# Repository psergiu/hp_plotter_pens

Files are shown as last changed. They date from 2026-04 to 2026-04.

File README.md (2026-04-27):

# HP Plotter Pens

3D-printed HP plotter pen models, using ballpoint pen refils.
Pros:
* easily available refills in multiple colors
* very thin lines
* less prone to dry out than ink pens
* much more writing distance per pen compared to ink pens
Cons:
* requires thicker paper else ball might not roll and leave ink on paper
* not suitable for points of very short lines (<1mm)
* very thin lines (not suitable for filling polygons or thick lines)

## Compatibility
The pens are compatible with the follwing plotters: 
* HP 9872
* HP 7440A ColorPro
* HP 7225
* HP 7470A
* HP 7475A
* HP 7550 (can be used with full-size uncut refills)
* HP 7090A Measurement Plotting System
* DEC LVP16
* IBM 7372
* IBM 6180

## Included models
### Bic Cristal refills
To be used with refills taken out of from Bic Cristal pens, available in multiple colors. Example: 
* https://www.amazon.com/BIC-MSBAPP241-Ballpoint-Assorted-24-Count/dp/B075CGYY5P/
* https://www.amazon.com/BIC-Cristal-Multicolour-Ballpoint-Point/dp/B07LF68GPR/

Cut off refill tube 3-4 mm above top of printed pen body - if you used white PETG, you can smear ink from the cut-off session on top of pen for easier identification. Warning: messy

### "Beadable Pen" refills
Those are short refills for the so-called "Badable" DIY pens. Available in black, blue & red in packs of 100+. Example:
* https://www.amazon.com/PASISIBICK-Plastic-Beadable-Refills-Writing/dp/B0CYLHZYT6/

The ink level in the refill tube is usually at the perfect so the tube can be shortened without causing a mess.

### Gell Ink refills
Work-In-Progress !

For gel pens, includes a stopper to keep the refill in place. 
Not fully tested yet, gel ink tends to seep out from the cut-off tubes if pens are not kept vertically and make a huge mess.

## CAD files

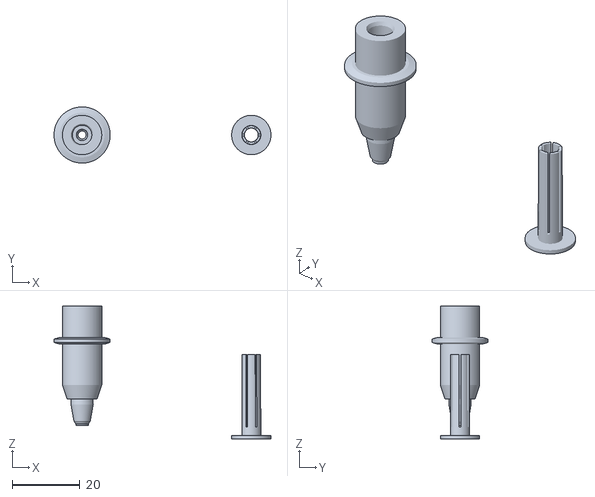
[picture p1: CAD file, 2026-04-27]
HP_pen-gel_refill.stl
64.1 x 16.6 x 39.2

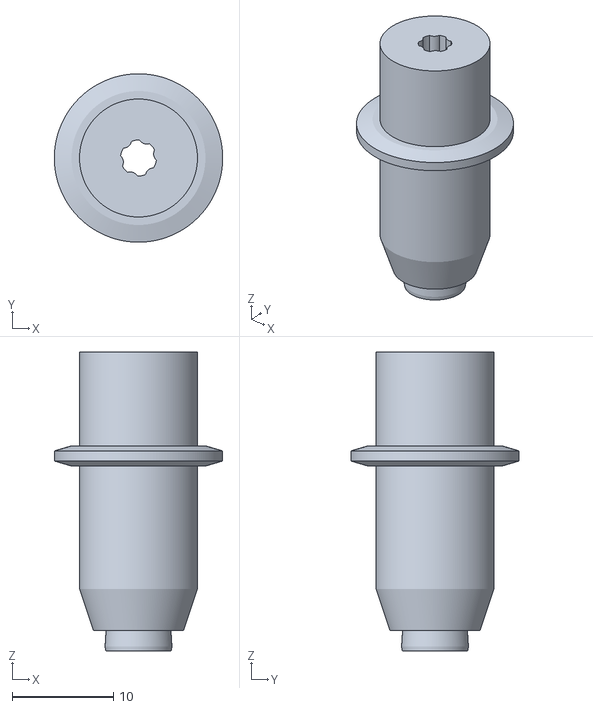
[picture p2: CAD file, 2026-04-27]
HP_pen-bic_cristal.stl
16.6 x 16.6 x 29.5

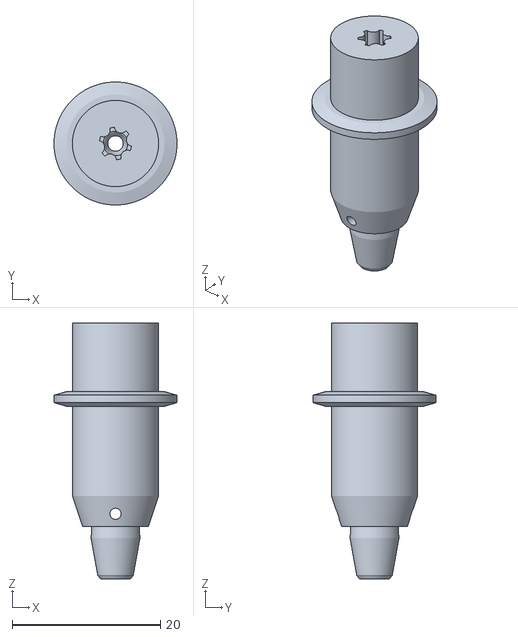
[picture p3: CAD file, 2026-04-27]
HP_pen-beadable_refill.stl
16.6 x 16.6 x 34.6

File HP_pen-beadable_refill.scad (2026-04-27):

// Beadable pen refill (62mm long, 44mm tip-to-end-of-ink)
// HP Plotter pen adapter 
//  by Sergiu Partenie
// - insert refill from top down
// - cut refill height to fit in pen path of plotter
// - print with tip facing up and concentric supports
// - reccomended material: PETg or similar non-brittle

$fn= 180;

//    ..............., pen_top_diameter ...............> |   | <,,  
//    :    ........... pen_diam                          |   |
//    :    :                                             |   |
//     _____  ........ top_cut_off_height                |   |
//    ||   |                                             |   |
//    ||   |                                             |   |
//    ||   |___                                          |   |
//    ||    __/  ..... ~ 27.7 mm to paper                |   |
//    ||   |                                             |   |
//    ||   |                                             |   |
//    ||   |                                             |   |
//    ||   |                                             |   |
//     |   |                                             [   ]
//     | . /  .........wiew_hole_height                  |   |
//   +-+ _/ .......... height_where_pen_diameter_change. \___/
//   |  /                                                 | | 
//   | /  ............ tip_height                         | |   
//   //                pen_bottom_diameter..............> | | <...
//  /'   ............. bottom_cut_off_height              | |
//                                                        \ /
// ------------------- ( paper ) --------------------------*--


total_body_height = 43.25 ; // fixed value, Official HP pen max height
pen_diam = 11.63 ; // official=11.5, HP pens=11.6. Adjust for filament shrinkage
pen_top_diameter = 4.35 ; 
pen_bottom_diameter = 3.25 ; 
tip_height = 2 ; // top of cone to squeeze metal tip for perfectly centered fit
pen_tip_diameter = 0 ; // adjust to enlarge metal tip squeeze cone. Default: 0

diameter_spacing = 0.05 ; // increase = easier to slide the pen. If you set it to 0 it will be very hard to get the pen in.

height_where_pen_diameter_change = 21.7 ; // Measured from the tip (ie. paper)
bottom_cut_off_height = height_where_pen_diameter_change - (22-5) ; 
top_cut_off_height = total_body_height - 4 ; // Top part of the pen, lower to allow handling refill tube

wiew_hole_height = 13.5 ; // height of view hole (for visually checking if refill is spent)

BodyOutline = [                     // X values = (measured diameter)/2, Y as distance from
    [0.0,0.0],                      //  0 fiber pen tip
//  [2.0/2,1.4],                    //  1 ... taper (not buildable)
    [1.0/2,0.005],                  //  1 ... faked point to remove taper
    [2.0/2,0.0],[2.0/2,2.7],        //  2 ... cylinder
    [3.7/2,2.7],[3.7/2,4.45],       //  4 tip surround
    [4.8/2,5.2],                    //  5 chamfer
    [6.6/2,10.2],                   //  6 seal seat    
    [6.4/2,11.8],                   //  7 rubber seal face
    [8.9/2,11.8],                   //  8 cap seat
    [pen_diam/2,15.9],              //  9 taper to body
    [pen_diam/2,28.0],              // 10 lower body
    [13.2/2,28.0],[16.6/2,28.5],    // 11 lower flange = 0.5
    [16.6/2,29.5],[13.2/2,30.0],    // 13 flange rim = 1.0
    [pen_diam/2,30.0],              // 15 upper flange = 0.5
    [pen_diam/2,43.25],             // 16 upper body
    [0.0,43.25]                     // 17 lid over reservoir
    ];

module adapter_body() {
 render(convexity=10)
        rotate_extrude()
            polygon(points=BodyOutline);
}

module adapter_minus_pen() {
    difference() {
        color ("white", 0.2) adapter_body () ;

        color ("red") translate([0,0,height_where_pen_diameter_change])
                    cylinder(r= (pen_top_diameter+diameter_spacing)/2, 
                             h= 100);

         color ("blue") translate([0,0,bottom_cut_off_height+tip_height])
                            cylinder(r=(pen_bottom_diameter+diameter_spacing)/2, 
                                 h=height_where_pen_diameter_change);

         // conical taper to squeeze metal refill tip
         color ("violet") translate([0,0,0.5]) cylinder(r1=(pen_tip_diameter+diameter_spacing)/2,
                                   r2=(pen_bottom_diameter+diameter_spacing)/2,
                                h=bottom_cut_off_height+tip_height);

        translate ([0, 0, bottom_cut_off_height/2]) 
            cube ([20, 20, bottom_cut_off_height], center=true) ;

        translate ([0, 0, 50/2 + top_cut_off_height]) 
            cube ([20, 20, 50], center=true) ;
    }
}

// to hold refill tube in place while also allowing easy replacement
//  if refill tube is moving freely it creates incorrect draw paths 
module guide() {
 translate([pen_bottom_diameter/2,-1.8,height_where_pen_diameter_change])
    cylinder(d=1.8,h=top_cut_off_height-height_where_pen_diameter_change);
}

union(){
 difference(){
  adapter_minus_pen();
  // sideways hole for visual inspection of ink level
  rotate([90,0,0])
    translate([0,wiew_hole_height,0])
     cylinder(d=1.5, h=12, center=true);
 }
 guide();
 rotate([0,0,60]) guide();
 rotate([0,0,120]) guide();
 rotate([0,0,180]) guide();
 rotate([0,0,240]) guide();
 rotate([0,0,300]) guide();
}

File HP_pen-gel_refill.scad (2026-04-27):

// Gel pen refill (128mm long, 7mm tip)
// HP Plotter pen adapter
//  by Sergiu Partenie
// - insert refill from top down
// - cut refill height to fit in pen path of plotter
// - print with tip facing up and concentric supports 

$fn= 180;

//                    refill_diam_tube ...............> |   | <..
//    ............... refill_diam_b ...............     |   |  
//    :   ........... pen_diam                    :     |   |
//    :   :                                       :     |   |
//     ____  ........ top_cut_off_height          :     |   |
//    /   |                                       :     |   |
//    |   |                                       :     |   |
//    |   |___                                    :     |   |
//    |    __/  ..... ~ 27.7 mm to paper          :     |   |
//    |   |                                       :     |   |
//    |   |                                       :     |   |
//    |   |                                       :     |   |
//    |   |                                       :     |   |
//    |   |                                       :.> __|___|__ <..
//  +-+   /   ....... refill_height_b ............... |_______|
//  |   _/                                              |   |
//  |  /              refill_diam_a ..................> |   | <....
// ++ /    .......... refill_height_a ..................\___/   
// | /                refill_diam_tip .................> | | <.....
// -'   ............. bottom_cut_off_height              | |
//                                                       \ /
// ------------------ ( paper ) --------------------------*--

total_body_height = 43.25 ; // fixed value, Official HP pen max height
pen_diam = 11.63 ; // official=11.5, HP pens=11.6. Adjust for filament shrinkage
bottom_cut_off_height = 4; // Measured from the tip (ie. paper)
top_cut_off_height = total_body_height - 4 ; // Top part of the pen, shorten

refill_diam_tip = 2.3 ; // width of bottom (tip) pen hole. Should be a tight (but removable) fit
refill_height_a = 7 ; // distance from paper where metal tip enters plastic tube 
refill_diam_a = 3.25; // diameter of plastic tube holding metal tip
refill_height_b = 13.76 ; // (0.16mm x 86 layers) Measured from the tip (ie. paper) to bottom of refill flange
refill_diam_b = 5.65 ; // width of the refill flange
refill_diam_tube = 4 ; // width of long refill tube

diameter_spacing = 0.05 ; // increase = easier to slide the refill. If you set it to 0 it will be very hard to get the refill in.

BodyOutline = [                     // X values = (measured diameter)/2, Y as distance from
    [0.0,0.0],                      //  0 fiber pen tip
//  [2.0/2,1.4],                    //  1 ... taper (not buildable)
    [1.0/2,0.005],                  //  1 ... faked point to remove taper
    [2.0/2,0.0],[2.0/2,2.7],        //  2 ... cylinder
    [3.7/2,2.7],[3.7/2,4.45],       //  4 tip surround
    [4.8/2,5.2],                    //  5 chamfer
    [6.6/2,10.2],                   //  6 seal seat    
    [6.4/2,11.8],                   //  7 rubber seal face
    [8.9/2,11.8],                   //  8 cap seat
    [pen_diam/2,15.9],              //  9 taper to body
    [pen_diam/2,28.0],              // 10 lower body
    [13.2/2,28.0],[16.6/2,28.5],    // 11 lower flange = 0.5
    [16.6/2,29.5],[13.2/2,30.0],    // 13 flange rim = 1.0
    [pen_diam/2,30.0],              // 15 upper flange = 0.5
    [pen_diam/2,43.25],             // 16 upper body
    [0.0,43.25]                     // 17 lid over reservoir
    ];

module adapter_body() {
 render(convexity=10)
        rotate_extrude()
            polygon(points=BodyOutline);
}

module adapter_minus_refill()
{
 difference()
  {
   color ("white", 0.2) adapter_body () ;

   // top pen hole
   color ("red")
    translate([0,0,refill_height_b])
     cylinder(d=refill_diam_b+diameter_spacing*2, h=100);

   // bottom pen hole
   color ("blue")
    translate([0,0,bottom_cut_off_height-diameter_spacing])
     cylinder(d=refill_diam_tip+diameter_spacing,h=refill_height_b-bottom_cut_off_height+2*diameter_spacing);

   // bottom (tip) cut-off line
   translate ([0, 0, bottom_cut_off_height/2]) 
    cube ([20, 20, bottom_cut_off_height], center=true) ;

   // top cut-off line
   translate ([0, 0, 50/2 + top_cut_off_height]) 
    cube ([20, 20, 50], center=true) ;

   // transition for easier refill insertion - bottom
   color ("violet")
    translate([0,0,refill_height_a-0.5])
     cylinder(d1=refill_diam_tip+diameter_spacing,d2=refill_diam_a,h=0.51);
  
   // tapered hole for plastic tube
   color ("blue") 
    translate([0,0,refill_height_a])
     cylinder(d1=refill_diam_a,d2=refill_diam_a+0.1,h=refill_height_b-refill_height_a+0.1);
     
   // transition for easier refill insertion - middle  
   color ("violet")
    translate([0,0,refill_height_b-0.5])
     cylinder(d1=refill_diam_a,d2=refill_diam_a+0.5,h=0.51);

   // transition for easier refill insertion - top   
   color ("violet")
    translate([0,0,top_cut_off_height-1])
     cylinder(d1=refill_diam_b,d2=refill_diam_b+1,h=1.1);
  }
}


// adapter
difference()
 {
  union()
   {
    adapter_minus_refill() ;
    // optional parts to add
   }
  // debug section view, comment out for final print
  // cube([20,20,100]);
 }


// refill stopper
translate([50,0,0])
 difference()
  {
    union()
     {
       // bottom flange
       cylinder(d=pen_diam, h=1);
       // stopper body, tapered
       cylinder(d1=refill_diam_b,d2=refill_diam_b-diameter_spacing-0.1,h=1+top_cut_off_height-refill_height_b-1.5);
     }

    // cuts in the stopper body 
    for(i=[0:60:120])
      translate([0,0,(top_cut_off_height-refill_height_b)/2+3.5])
       rotate([0,0,i])
        cube([10,0.5,top_cut_off_height-refill_height_b],center=true);

    // hole for refill tube, tapered
    cylinder(d1=refill_diam_tube+diameter_spacing,d2=refill_diam_tube+diameter_spacing+0.1,h=top_cut_off_height-refill_height_b+1);
  }
  
 

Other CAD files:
HP_pen-bic_cristal.scad

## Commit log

2026-04-27 Initial .scad file upload
    [HP_pen-beadable_refill.scad, HP_pen-bic_cristal.scad, HP_pen-gel_refill.scad]
2026-04-27 Initial .stl upload
    [HP_pen-beadable_refill.stl, HP_pen-bic_cristal.stl, HP_pen-gel_refill.stl]
